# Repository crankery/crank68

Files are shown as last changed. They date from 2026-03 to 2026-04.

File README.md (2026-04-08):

# C68

One day I thought to myself I want to build a computer with the simplest 8 bit CPU I can think of". That CPU is the Motorola M6800 and this is the computer.

It's going to be pretty useless but it's fun to play around with all of this.

## Hardware

So, this isn't intended to be historically accurate or anything. It's a 1970s CPU but I'll use modern components where it makes things simpler. So, for whatever reason I thought it'd be nice to use things like the MC6850, MC6821 and other components that would have been available when the M6800 was being used in the industry. But really, I'm just trying to avoid using microcontrollers that would render the actual CPU hopelessly redundant.

One place I used a microcontroller is on the terminal board. It's just being used to produce DVI video and render text. Oh, it also does the keyboard matrix scan. It has its one job and that's to replace a glass terminal. So, since it's busy doing dumb terminal stuff it doesn't really matter that it's anacronistic... right?

The computer is split up across a bunch of 100x100mm boards. This is an attempt to reduce the cost of production as that's the maxiumum size the Chinese fabs will produce at bargain pricing. The one exception (thus far) is the actual keyboard; its dimensions are dictated by the keyboard layout.

I'm currently using some SPLDs as there were analogs of these back in the day. I am using them for decode logic for the most part but I'm trying to replace them with simple 74 series logic slowly.

### Boards

As previously mentioned, the computer is built upon a set of cards. These cards are generally single function so there's a lot of them. 

#### Backplane

The backplane is a simple board with a bunch of slots on it. Each board will plug into this board. The boards are setup to be chained together. The slots are 13.5mm apart giving about 12mm of component height for each board. If a board grows taller than this or has multiple layers, it will block the next slot. This is tall enough to allow for most common components though.

The left side of each board is allowed to host connectors. This allows for connecting I/O devices to individual boards such as parallel ports, serial ports, video output or sound output.

Status: C68BP.01 sent to production

#### Processor

This board hosts the Motorola M6800 CPU and the MC6875 clock generator along with an oscillator running at 4MHz. This will result in a 1MHz system clock.

Status: C68CPU.01 sent to production

#### Memory

Lower 48KB of RAM (in FRAM), 8KB ROM (EEPROM)

Status: C68MEM.01 sent to production

#### Banked Memory

1 MB of batery backed SRAM presented in two four KB windows in the main address space.

Status: Finalized design

#### Math

AMD AM9511 FPU

Status: design in progress

#### Sound

This is a sound board. I'm still trying to decide which chip(s) to use. The YM2149 OPL2, Philips SAA1099, GI AY-3-8910 SGM

Status: spitballing

#### IO

2xACIA MC6850, 2xPIA MC6821

Status: design completed

#### Time

A DS12885 RTC and a MC6850 PTC.

Status: design completed

#### Front Panel

blinkenlights and switches and buttons.

Status: in progress

#### Terminal

Using a Raspberry PI Pico with PicoDVI to generate the terminal's video and to perform keyboard scans. Uses an on-board MC6850 for communication to the host system.

Status: sent to production

## Software

The software for this project includes some old stuff and some new stuff. The old stuff is being "translated" into a VASM 6800 standard syntax while the new stuff is being written that way.

### Emulator

emu is a very basic M6800 emulator and is being used to verify software development. It isn't complete yet and will halt when it encounters an unimplemented instruction.

It is designed to match the actual computer's IO and memory access and will do the minimum to make things appear as they will in reality. So, the ACIA status and control registers set the flags appropriately while the actual rate of transfer isn't worried about.

### New Stuff

#### C68 BIOS

### Old Stuff

#### MIKBUG2

#### Micro Basic

## Tools

Everything is being done using open source tools. This includes, but is not limited to:

- kicad
- vasm
- vlink
- galasm
- minipro
- GCC

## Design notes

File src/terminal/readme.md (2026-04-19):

# pico-sdk

added as submodule here

we're just using this to build the picodvi so there's no point installing it globally.

to build the pico-sdk:

```sh
cd pico-sdk
git submodule update --init  
cmake -S . -B build
```

# picodvi

added as sumbodule here

```sh
cd picodvi/software
mkdir build
cd build
PICO_SDK_PATH=../../../pico-sdk cmake -DPICO_COPY_TO_RAM=1 ..
```

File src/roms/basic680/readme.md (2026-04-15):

# Altair 680 BASIC / Micro-soft BASIC for 6800

This is taken from https://gitlab.com/retroabandon/altair-680-basic which was an ambitious project to restore the assembly
source from a binary of Microsoft basic for the Altair 680 computer.

I'm trying to get assembling with vasm6800_oldstyle to run on my 6800 computer.

So, we're starting with a rough disassembly file. Getting this to build to match the binaries it was made from is the first goal.

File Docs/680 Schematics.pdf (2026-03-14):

9 | 8 | 7 | 6 | 5 | 4 | 3 | 2

§]

R/W-P

I

I

12 • | 2 I .. '-" | R/W"'! 13 | M | 0--.....- | .... _.. 2-C9, 3-09

-2 MHZ

-7 | 4'--- I
vce | TT
TbT | a
K 10 | 13 Q | II

9

8

. '---0

5

::10_

_3

CI2 50 pF

___ XTAL2

I-- | 2 MHZ
...1.. I | t | 6 | 10 | 6 | 4 | 2 | 10
9I yy | • 3 | 5 | 7 | 9 | II | 13 | 13 | II
tIW | I Ww. | yy | -
2 | 4 | 6 | "10 | If----+,:....:4-+_-f-lJ:::.2_--' ---4' | L.-...4.

J... C9

-,.. 430 pF .. R24

470 J\.

Q4
.... | R25 ... | 4 : .. 470.n- | 6
VC C ... | .. .. | R29 .. .. R 26 | 100 .no | --J
.. | 470 A | ..
..... | . Q':t :t | __8---\
:;r:. I OOI | 9 1ss R27 | JJF

4IIl" 470 A ,,:"
... | CIO
II 430 pF I
.... ,.,.,.,. ...

47.n..

I

:: RIO
.... 'OK ...

## vee

,-0
:.. R20 :

3.3K .

7

6
pp ;--0

IK ....

4 | 39 | 7 | 5 | 6 | 34 | 3 | 37 | 36 | 40
IRQ | TSC | BA | VMA | NMI | R/W | 01 | 02 | OBE | RES
6800 | NN
AI | A2 | A3 | A4 | A5 A6 | A7 A8 | A9 | AIO | All AI2 | AI3 AI4 | Al5 00 | 01 | 02 | 03 | 04 | 05 | 06 | 07
10 | II | 12 | 13 | 14 | 15 | 16 | 17 | 18 | '9 | 20 22 | 23 | 24 | 25 | 33 | 32 | 31 | 30 29 | 28 | 27 | 26
r--- | 2-D4, 3-C I
I 1..--- | 2-04, 3-C I
L--_a---------I | B05:-; | 2-04,3-CI ___---f----------I
B04 | 2-04, 3-CI
___ | .... 2-04,3-CI
S02 | 2-04,3-CI
F - 70-."'- r04 '-=- rl.-4-=- -;:;.- - rl.-.r rl.-....- | rl.- | rl.-.....- | -l'=- - | - •..=- | - ..-.... | I | SOl =- 2-04,3-CI
I lIIl>.... | | | ... | ... | >:. | :> 0!lI. | ..>.... | .. | 0Ill. | ..» | 4ll,. | ........ | ..> | .. | .. | .. | ... | ...> | ...> | .. | ... | ... PACKS | I | B00
:>:. | :..:. | :> | .. >.... | ...>..... | .. | ...> | .. | :.. | :> | :> | 1-4 | I | 2-04,3-CI
I ... > | .. | > | .. | .. | > | .... | .. .. | .. | ... | ... | ... | .. | ..... | <II> | ... | <l!" | ...> | ...> | 4.7 K
...: | : | : | : | : | : | : | : | ... : | : | ...::: | :::: | : : | :: | :::: | :::: | :::: | :: | :: | : | ... : | " | ...: | <II: | : | :-c: | I
L- | -_------------------------ --

vee ...-:111--1.--__--+--.....-+----+---+----+---..--+----

2-C9, 3-A4

2-C9,3-A4

2-C9,3-A5 ::---+----+---w

2-C9,3-AS

2-C9,3-A6

2

### 8 HALT -

F A'

9

2-09,
2-09,

2-09,3-

2-09,3-AS

2-09,

I | 2-09,3
| 2-09,3
| 2-09, 2-C9,3-A4 .:

c

HALT | IRQ | T-se | BA | VMA | NMJ | Riw | ,pI | 92 | DBE | RES
/ | I | I | /\ | Ii'- | I | /\ | l' 1 | I
2-AS ..:; lSI | (12::: | C9
D | C9 :: R/W | r Z

2- | 09
2- A4_ TRQ | 3 | 5 | A23
2- 84 | ..A ••••
| ,.,.,.,.
10 | 47.n.
pp

9

\j; | tv | I | I | I
\V \/ | \( \/ | \V \/ | \/ \V | \V \V | \V \V | V \/ | ¥W | \t' \V | \/ \V | \l;
A¢ | Ai | A2 | A3 | A4 | A5 AS | A7 | AS | A9 | AIO | All Af2 | AI3 AI4 | AI5 | Df | 02 | D3 04 | 05 | 06 | D7
[!]@] | EJEO

\V

BO¢

\/

BOI

\/

BD 2
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
SO 6

\v

B07 | 68"0 COMPUTER SCHEMATIC
ACR | 5-4-76

9 | 8 | 7 | 6 | 3 | 2

J I

+5V
R401
IK

R202
IK

R204
470..n..

R203
220..n..

JI

.--,

I | 4 | I
E4 | -:::::=v-;---

L __ .J

-16V

R303
3.3 K

+5V

.....----I ,.. '_ .,

I 3 I
______E::.-3__-:-.:

L __ .J

+5V

6

.... ES'

L | .J

E5

RIOI
220..1\..
RS 232

!

... I-BI
i- B I

L...---...;;;..-.......
1- B1
I-AI
I- AI
1- AI
1- AI

## IRQ

I-D9

2 Rx
DATA
Rx | 3
II | RS | elK
4 13 R/W | Tx
| | ClK
E
14 | +5V

t5V

MM
13 | 12 | 10 CSt
.jJ

I
t::

R21
IS...n..

+5V

2W
+SV (VCC) | 8

RS 232

+

6

C3
35j1F
15V

VCC
6

R9
4.7K -9V +5V

C5
+ 100jJF

2

10

# a-=------------.-TII-..,..----=-4l-

U

u ",,--S---a._-+--_

:3

B

AI5
1-89.3-A7
Al4
1- B9, 3-A7
AI3
1-89.3-A7
D | Al2
1- B 9, 3-A8
| All
1-89.3-A8
| AIO
1- B9, 3- A8
| A9
I-B9,3-A6
| A 8
1-89,3-A6
| VMA
1-08
A7 1-89,3-A5
| A 6
1-89,3-A5
AS 1-89,3-AS
| A4
1- 89, 3-A5
| A3
1-89,3-A5
A2 I-A9,3-A5
| AI
1- A9, 3-A5
C | A0
1- A9. 3-A6
R/W 1-07

02 1-06

| R/W-P
1- BI • 3-D 9

## [!gJ -16 V

+16V

@] +9V

9 | 8 | 7 | 5 | 4 | 3 | 2
REF | TYPE | GNO
A.B,C,D,r | 74LS05 | 14 | 7
H/13, E/13 | 4009 OR | 16 | 8 F/13,G/13 | 4049
.1/11,12,13 74LOO | 14 | 7
K/II,12 | 74LI23 | 16 | 8 L/3,4,11,12

....----+--+----+--+-1680 0ISPLAY SCHEMATIC

DO EJ

01

02

03

04

05

06 §J

07

02

GNO 150,1001

VCC

L027
(HALT)

R34
lOOK

Q

## vec

CLR
II | R39 | VCC
10K | f::l L..- | --+ | ---< QJ I I.!!J

LDI7

Q 13

CLR

RESET rs4l OP

Q

9

## vee

CLR
II

R40
10K

## vee

VCC

Q 13

R33
4.7
(RUN) | R41 0 | lOA-
(DEP) | S2:(HALTl
I J: | 2 | II I- | 10

B RI7
| 20K | , (HALT)
510 | RIO
___

# §lSA

A

0
AO

At

@] A2

A3

A4

A5

C
@] A6

0 A7

# §l AS

(2JA9

o AIO

o All

B
§] AI2

AI3

§] AI4

§] AIS

.---+-+-----t----t--1 A. C. R.

680-100
SHT40F4

••fO"_ATtO •••T.oaTIIO.TMlaDOCU•••TAW. TNt: DWa.. itO. P.OPI..Tl' O,. ••T•• I.C. A.D.N...LL.OT ••••••ODUCI:D

'O•••,..".."O.lEOy.... TM... TMAT'O••"ICM ITW.I

•• | WIT"OUT Till! •••TT•• --;- | ----. | --;--_---.----__

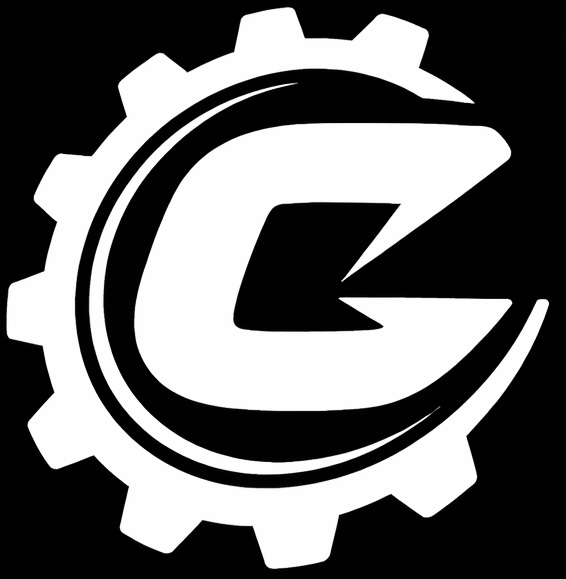
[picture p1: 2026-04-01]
Docs/Crank.jpg

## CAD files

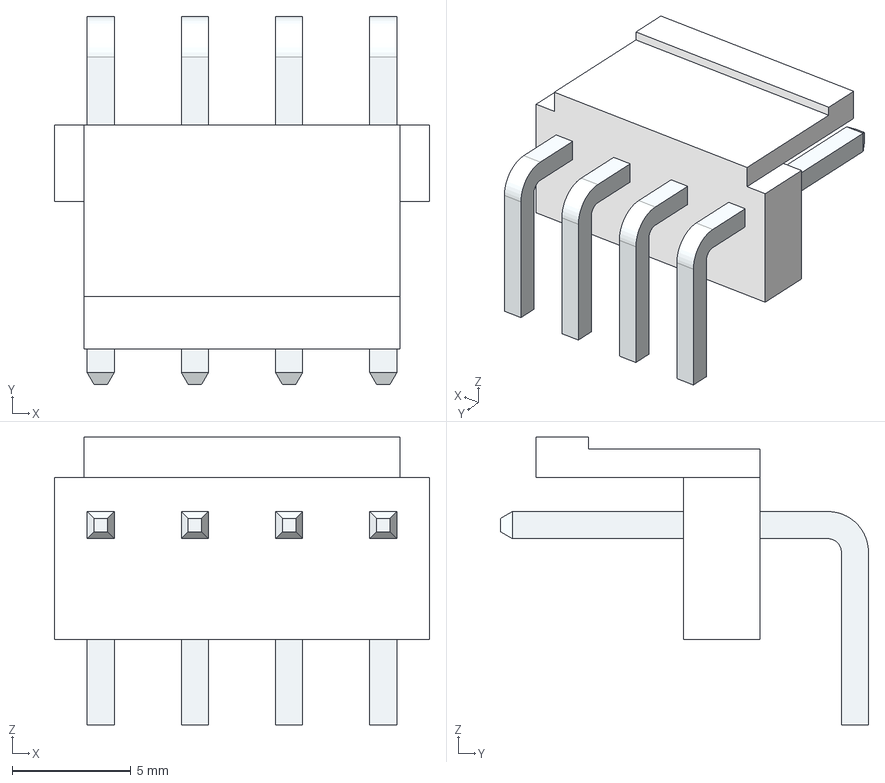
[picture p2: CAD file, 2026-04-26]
3D/B4PS-VH.stp
15.8 x 15.5 x 12.1 mm

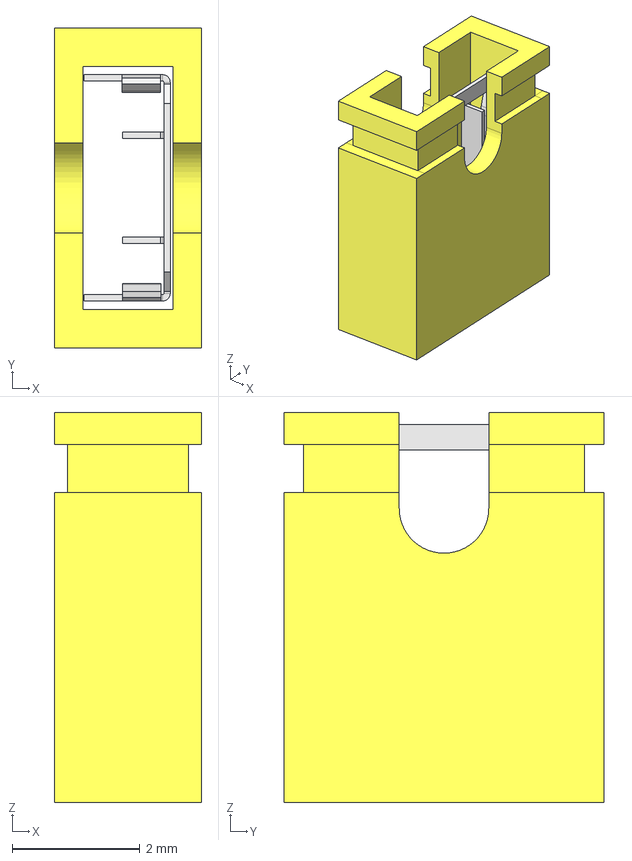
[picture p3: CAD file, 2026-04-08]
3D/Jumper.step
2.30 x 5.00 x 6.10 mm
Frame
Jump

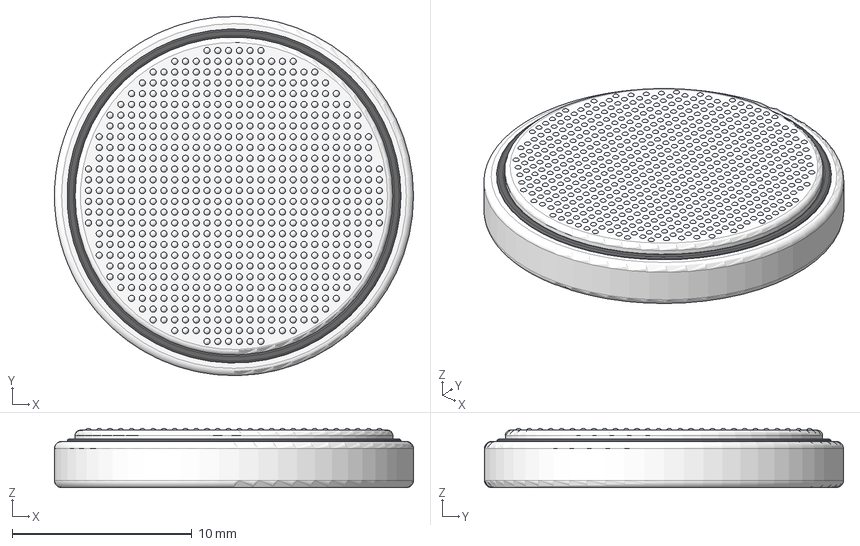
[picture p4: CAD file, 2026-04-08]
3D/CR2032.step
20.0 x 20.0 x 3.30 mm

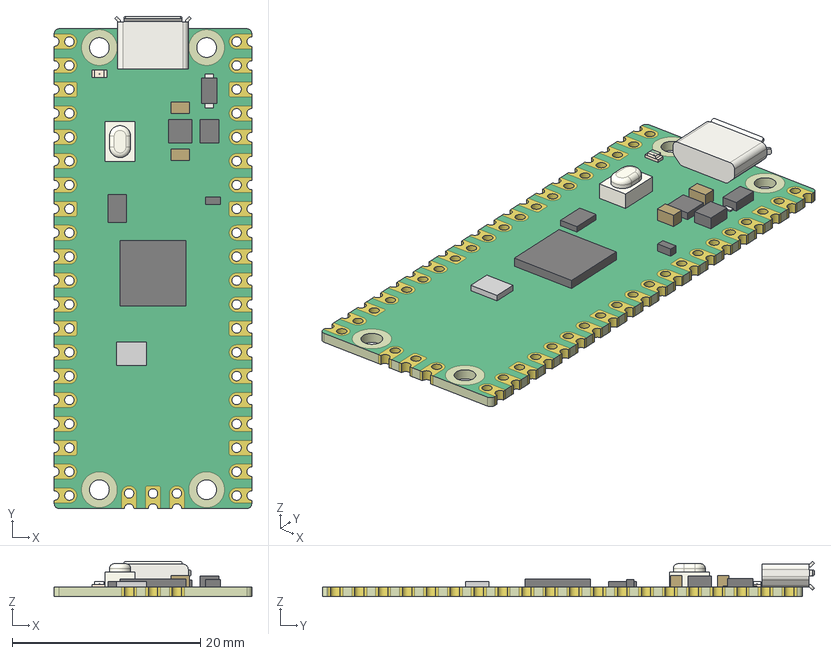
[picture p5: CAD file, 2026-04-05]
3D/RaspberryPi_Pico.step
21.0 x 52.3 x 3.75 mm

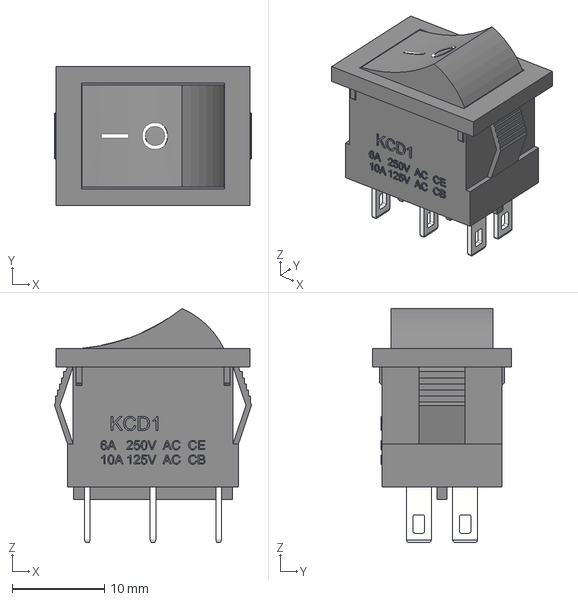
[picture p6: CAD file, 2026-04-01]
3D/Rocker Switch 11.step
21.3 x 15.0 x 25.3 mm

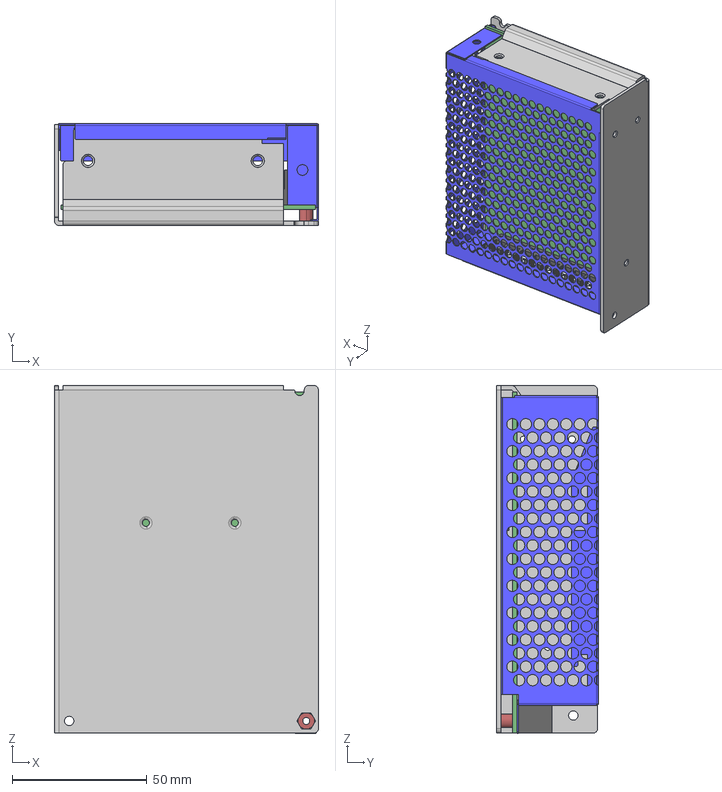
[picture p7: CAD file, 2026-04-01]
3D/RT-65.stp
98.1 x 37.8 x 129.2 mm
DUNZI-S-8P_1.PRT
RG-65-PCB_1.PRT
CUUU_1.PRT
90T-T_6.PRT
903-D_11.PRT

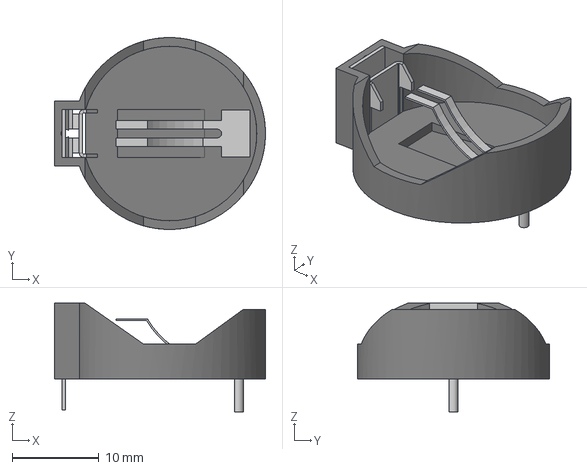
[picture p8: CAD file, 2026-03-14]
3D/KLS5-CR2032-01 battery holder.stp
24.3 x 22.1 x 12.5 mm

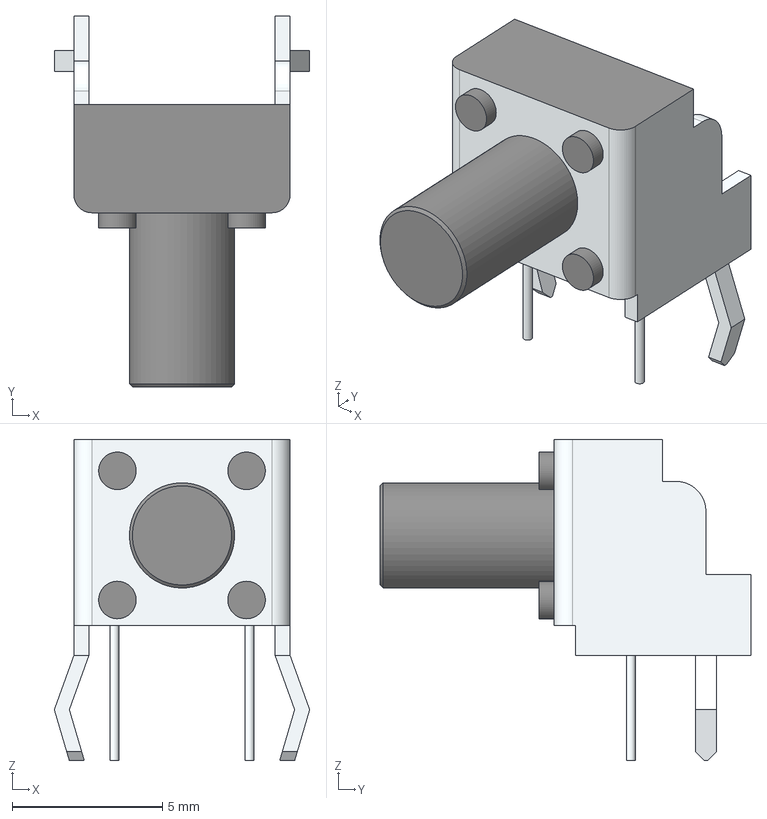
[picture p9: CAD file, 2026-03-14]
3D/SW-DTSA-65K-V.stp
8.50 x 12.3 x 10.7 mm

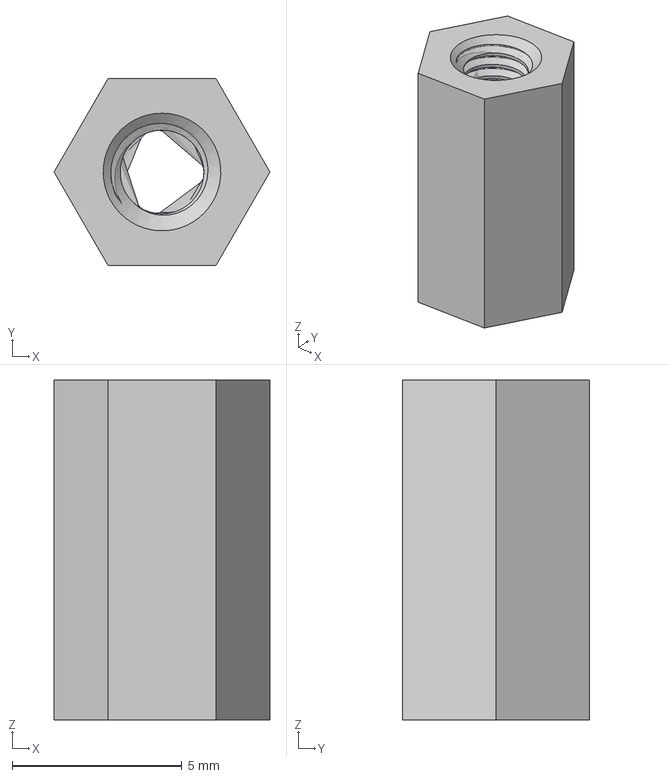
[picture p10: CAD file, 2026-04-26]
3D/hex spacer standoff nut_M3 L10.stp
6.35 x 5.50 x 10.0 mm

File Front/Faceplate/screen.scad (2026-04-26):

$fn = 32;

panel_w = 118.0;
panel_h = 89.0;
panel_d = 6.0;

bezel_w = 5;
overall_d = 8;

insert_hole_d = 3.5;

bighole_d =  (panel_w - bezel_w / 4) / 5;

difference() {
    cube([panel_w+bezel_w*2, panel_h+bezel_w*2, overall_d]);
    translate([bezel_w, bezel_w, -0.1])
      cube([panel_w, panel_h, panel_d]);
  
  translate([2.5-1.75, bezel_w/2 + insert_hole_d/2, -0.1])
    cylinder(h = overall_d + 1, r = insert_hole_d / 2, center = true);
  
  translate([panel_w  + bezel_w + insert_hole_d/2,(bezel_w/2 + insert_hole_d)/2, -0.1])
    cylinder(h = overall_d + 1, r = insert_hole_d / 2);  
  
  // save some plastic...
  translate([bezel_w * 2 + bighole_d / 2, bezel_w * 2 + bighole_d / 2, 0.1])
    cylinder(h = 10, , r = bighole_d / 2);

  translate([bezel_w * 2 + bighole_d / 2, bezel_w * 2 + bighole_d / 2, 0.1])
    cylinder(h = 10, , r = bighole_d / 2);

  translate([bezel_w * 3 + bighole_d +  bighole_d / 2, bezel_w * 2 + bighole_d / 2, 0.1])
    cylinder(h = 10, , r = bighole_d / 2);

  translate([bezel_w * 4 + bighole_d* 2 +  bighole_d / 2, bezel_w * 2 + bighole_d / 2, 0.1])
    cylinder(h = 10, , r = bighole_d / 2);

  translate([bezel_w * 5 + bighole_d* 3 +  bighole_d / 2, bezel_w * 2 + bighole_d / 2, 0.1])
    cylinder(h = 10, , r = bighole_d / 2);
    
  translate([bezel_w * 2 + bighole_d / 2, bezel_w * 3 + bighole_d + bighole_d / 2, 0.1])
    cylinder(h = 10, , r = bighole_d / 2);

  translate([bezel_w * 3 + bighole_d +  bighole_d / 2, bezel_w * 3 + bighole_d + bighole_d / 2, 0.1])
    cylinder(h = 10, , r = bighole_d / 2);

  translate([bezel_w * 4 + bighole_d* 2 +  bighole_d / 2, bezel_w * 3 + bighole_d + bighole_d / 2, 0.1])
    cylinder(h = 10, , r = bighole_d / 2);

  translate([bezel_w * 5 + bighole_d* 3 +  bighole_d / 2, bezel_w * 3 + bighole_d + bighole_d / 2, 0.1])
    cylinder(h = 10, , r = bighole_d / 2);
    
  translate([bezel_w * 2 + bighole_d / 2, bezel_w * 4 + bighole_d * 2 + bighole_d / 2, 0.1])
    cylinder(h = 10, , r = bighole_d / 2);

  translate([bezel_w * 3 + bighole_d +  bighole_d / 2, bezel_w * 4 + bighole_d * 2+ bighole_d / 2, 0.1])
    cylinder(h = 10, , r = bighole_d / 2);

  translate([bezel_w * 4 + bighole_d* 2 +  bighole_d / 2, bezel_w * 4 + bighole_d * 2+ bighole_d / 2, 0.1])
    cylinder(h = 10, , r = bighole_d / 2);

  translate([bezel_w * 5 + bighole_d* 3 +  bighole_d / 2, bezel_w * 4 + bighole_d * 2+ bighole_d / 2, 0.1])
    cylinder(h = 10, , r = bighole_d / 2);
}

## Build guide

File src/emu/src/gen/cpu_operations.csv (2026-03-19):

opcode_byte | mnemonic | addr_mode | cycles
0x01 | nop | inh | 2
0x06 | tap | inh | 2
0x07 | tpa | inh | 2
0x08 | inx | inh | 2
0x09 | dex | inh | 2
0x0a | clv | inh | 2
0x0b | sev | inh | 2
0x0c | clc | inh | 2
0x0d | sec | inh | 2
0x0e | cli | inh | 2
0x0f | sei | inh | 2
0x10 | sba | inh | 2
0x11 | cba | inh | 2
0x16 | tab | inh | 2
0x17 | tba | inh | 2
0x19 | daa | inh | 2
0x1b | aba | inh | 2
0x20 | bra | rel | 3
0x22 | bhi | rel | 3
0x23 | bls | rel | 3
0x24 | bcc | rel | 3
0x25 | bcs | rel | 3
0x26 | bne | rel | 3
0x27 | beq | rel | 3
0x28 | bvc | rel | 3
0x29 | bvs | rel | 3
0x2a | bpl | rel | 3
0x2b | bmi | rel | 3
0x2c | bge | rel | 3
0x2d | blt | rel | 3
0x2e | bgt | rel | 3
0x2f | ble | rel | 3
0x30 | tsx | inh | 2
0x31 | ins | inh | 2
0x32 | pula | inh | 2
0x33 | pulb | inh | 2
0x34 | des | inh | 2
0x35 | txs | inh | 2
0x36 | psha | inh | 2
0x37 | pshb | inh | 2
0x39 | rts | inh | 5
0x3b | rti | inh | 9
0x3e | wai | inh | 9
0x3f | swi | inh | 12
0x40 | nega | inh | 2
0x43 | coma | inh | 2
0x44 | lsra | inh | 2
0x46 | rora | inh | 2
0x47 | asra | inh | 2
0x48 | asla | inh | 2
0x49 | rola | inh | 2
0x4a | deca | inh | 2
0x4c | inca | inh | 2
0x4d | tsta | inh | 2
0x4f | clra | inh | 2
0x50 | negb | inh | 2
0x53 | comb | inh | 2
0x54 | lsrb | inh | 2
0x56 | rorb | inh | 2
0x57 | asrb | inh | 2
0x58 | aslb | inh | 2
0x59 | rolb | inh | 2
0x5a | decb | inh | 2
0x5c | incb | inh | 2
0x5d | tstb | inh | 2
0x5f | clrb | inh | 2
0x60 | neg | idx | 4
0x63 | com | idx | 4
0x64 | lsr | idx | 4
0x66 | ror | idx | 4
0x67 | asr | idx | 4
0x68 | asl | idx | 4
0x69 | rol | idx | 4
0x6a | dec | idx | 4
0x6c | inc | idx | 4
0x6d | tst | idx | 4
0x6e | jmp | idx | 4
0x6f | clr | idx | 4
0x70 | neg | ext | 4
0x73 | com | ext | 4
0x74 | lsr | ext | 4
0x76 | ror | ext | 4
0x77 | asr | ext | 4
0x78 | asl | ext | 4
0x79 | rol | ext | 4
0x7a | dec | ext | 4
0x7c | inc | ext | 4
0x7d | tst | ext | 4
0x7e | jmp | ext | 4
0x7f | clr | ext | 4
0x80 | suba | imb | 2
0x81 | cmpa | imb | 2
0x82 | sbca | imb | 2
0x84 | anda | imb | 2
0x85 | bita | imb | 2
0x86 | ldaa | imb | 2
0x88 | eora | imb | 2
0x89 | adca | imb | 2
0x8a | oraa | imb | 2
0x8b | adda | imb | 2
0x8c | cpx | imw | 3
0x8d | bsr | rel | 7
0x8e | lds | imw | 3
0x90 | suba | dir | 3
0x91 | cmpa | dir | 3
0x92 | sbca | dir | 3
0x94 | anda | dir | 3
0x95 | bita | dir | 3
0x96 | ldaa | dir | 3
0x97 | staa | dir | 3
0x98 | eora | dir | 3
0x99 | adca | dir | 3
0x9a | oraa | dir | 3
0x9b | adda | dir | 3
0x9c | cpx | dir | 3
0x9e | lds | dir | 3
0x9f | sts | dir | 3
0xa0 | suba | idx | 4
0xa1 | cmpa | idx | 4
0xa2 | sbca | idx | 4
0xa4 | anda | idx | 4
0xa5 | bita | idx | 4
0xa6 | ldaa | idx | 4
0xa7 | staa | idx | 4
0xa8 | eora | idx | 4
0xa9 | adca | idx | 4
0xaa | oraa | idx | 4
0xab | adda | idx | 4
0xac | cpx | idx | 4
0xad | jsr | idx | 6
0xae | lds | idx | 4
0xaf | sts | idx | 4
0xb0 | suba | ext | 4
0xb1 | cmpa | ext | 4
0xb2 | sbca | ext | 4
0xb4 | anda | ext | 4
0xb5 | bita | ext | 4
0xb6 | ldaa | ext | 4
0xb7 | staa | ext | 4
0xb8 | eora | ext | 4
0xb9 | adca | ext | 4
0xba | oraa | ext | 4
0xbb | adda | ext | 4
0xbc | cpx | ext | 4
0xbd | jsr | ext | 7
0xbe | lds | ext | 4
0xbf | sts | ext | 4
0xc0 | subb | imb | 2
0xc1 | cmpb | imb | 2
0xc2 | sbcb | imb | 2
0xc4 | andb | imb | 2
0xc5 | bitb | imb | 2
0xc6 | ldab | imb | 2
0xc8 | eorb | imb | 2
0xc9 | adcb | imb | 2
0xca | orab | imb | 2
0xcb | addb | imb | 2
0xce | ldx | imw | 3
0xd0 | subb | dir | 3
0xd1 | cmpb | dir | 3
0xd2 | sbcb | dir | 3
0xd4 | andb | dir | 3
0xd5 | bitb | dir | 3
0xd6 | ldab | dir | 3
0xd7 | stab | dir | 3
0xd8 | eorb | dir | 3
0xd9 | adcb | dir | 3
0xda | orab | dir | 3
0xdb | addb | dir | 3
0xde | ldx | dir | 3
0xdf | stx | dir | 3
0xe0 | subb | idx | 4
0xe1 | cmpb | idx | 4
0xe2 | sbcb | idx | 4
0xe4 | andb | idx | 4
0xe5 | bitb | idx | 4
0xe6 | ldab | idx | 4
0xe7 | stab | idx | 4
0xe8 | eorb | idx | 4
0xe9 | adcb | idx | 4
0xea | orab | idx | 4
0xeb | addb | idx | 4
0xee | ldx | idx | 4
0xef | stx | idx | 4
0xf0 | subb | ext | 4
0xf1 | cmpb | ext | 4
0xf2 | sbcb | ext | 4
0xf4 | andb | ext | 4
0xf5 | bitb | ext | 4
0xf6 | ldab | ext | 4
0xf7 | stab | ext | 4
0xf8 | eorb | ext | 4
0xf9 | adcb | ext | 4
0xfa | orab | ext | 4
0xfb | addb | ext | 4
0xfe | ldx | ext | 4
0xff | stx | ext | 4

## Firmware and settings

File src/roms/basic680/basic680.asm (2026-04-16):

; f9dasm: M6800/1/2/3/8/9 / H6309 Binary/OS9/FLEX9 Disassembler V1.79
; Loaded Motorola S file basic680.mot

;****************************************************
;* Used Labels                                      *
;****************************************************

M1B1B   EQU     $1B1B
M22F1   EQU     $22F1
M2505   EQU     $2505
M2E4F   EQU     $2E4F
M2FC1   EQU     $2FC1
M3BD7   EQU     $3BD7
M46BD   EQU     $46BD
M49C4   EQU     $49C4
M52C7   EQU     $52C7
M55C6   EQU     $55C6
M6828   EQU     $6828
M7960   EQU     $7960
M7A88   EQU     $7A88
M7D5A   EQU     $7D5A
M7D9A   EQU     $7D9A
M7FFF   EQU     $7FFF
M8180   EQU     $8180
M8607   EQU     $8607
M863F   EQU     $863F
M8D97   EQU     $8D97
M942E   EQU     $942E
M9474   EQU     $9474
MA100   EQU     $A100
MC608   EQU     $C608
MC60E   EQU     $C60E
MC628   EQU     $C628
MC62C   EQU     $C62C
MDE9E   EQU     $DE9E
ME47F   EQU     $E47F
MEA60   EQU     $EA60
MF002   EQU     $F002
MF600   EQU     $F600
MFC18   EQU     $FC18
INCH    EQU     $FF00
POLCAT  EQU     $FF24
OUTCH   EQU     $FF81
MFFFF   EQU     $FFFF

;****************************************************
;* Program Code / Data Areas                        *
;****************************************************

        ORG     $0000

START   SEC
        ROR     >M00F3
RDYJSR  JMP     INIT                     ; !!! INIT replaces with JSR READY (warm start)
M0007   JMP     Z033C
M000A   FCB     $00
M000B   FCB     $00
M000C   FCC     "H"
M000D   FCC     "8"
M000E   FCB     $00
M000F   FCC     ","
M0010   FCB     $00,$00,$00,$00,$00,$00,$00,$00,$00,$00,$00,$00,$00
        FCB     $00,$00,$00,$00,$00,$00,$00,$00,$00
M0026   FCB     $00,$00,$00,$00,$00,$00,$00,$00,$00,$00,$00,$00,$00
        FCB     $00,$00
M0035   FCB     $00,$00,$00,$00,$00,$00,$00,$00,$00,$00,$00,$00,$00
        FCB     $00
M0043   FCB     $00,$00,$00,$00,$00,$00,$00,$00,$00,$00,$00,$00
M004F   FCB     $00,$00,$00,$00,$00,$00,$00,$00,$00
CHARAC  FCB     $00
ENDCHR  FCB     $00
M005A   FCB     $00
M005B   FCB     $00
M005C   FCB     $00
M005D   FCB     $00
M005E   FCB     $00
M005F   FCB     $00
M0060   FCB     $00
TEMPPT  FCB     $00,$00
M0063   FCB     $00,$00
M0065   FCB     $00,$00,$00,$00,$00,$00,$00,$00,$00,$00,$00,$00
M0071   FCB     $00
M0072   FCB     $00
M0073   FCB     $00
M0074   FCB     $00
M0075   FCB     $00
M0076   FCB     $00
M0077   FCB     $00
stktmp  FCB     $00                      ; temp storage for S when using for copy
M0079   FCB     $00
M007A   FCB     $00
M007B   FCB     $00
M007C   FCB     $00
M007D   FCB     $00
M007E   FCB     $00
M007F   FCB     $00
M0080   FCB     $00
M0081   FCB     $00
M0082   FCB     $00
M0083   FCB     $00
M0084   FCB     $00
M0085   FCB     $00
M0086   FCB     $00,$00
M0088   FCB     $00
M0089   FCB     $00
M008A   FCB     $00
M008B   FCB     $00
M008C   FCB     $00,$00
M008E   FCB     $00
M008F   FCB     $00
M0090   FCB     $00
M0091   FCB     $00
M0092   FCB     $00,$00
M0094   FCB     $00
M0095   FCB     $00
M0096   FCB     $00,$00
M0098   FCB     $00,$00
M009A   FCB     $00
M009B   FCB     $00
M009C   FCB     $00
M009D   FCB     $00
M009E   FCB     $00
M009F   FCB     $00
M00A0   FCB     $00,$00
M00A2   FCB     $00
copy_dsttop FCB     $00,$00                  ; top of destination range for `copy`
copy_srctop FCB     $00,$00                  ; top of source range for `copy`
copy_dstbot FCB     $00,$00                  ; bottom of dest range for copy
                                         ;   (filled in at end of `copy`)
copy_srcbot FCB     $00,$00                  ; 1 below bottom of dest range for `copy`
M00AB   FCB     $00
M00AC   FCB     $00
M00AD   FCB     $00
M00AE   FCB     $00
tmpstrlen FCB     $00
DSCTMP  FCB     $00,$00
M00B2   FCB     $00
M00B3   FCB     $00
M00B4   FCB     $00
M00B5   FCB     $00
M00B6   FCB     $00
M00B7   FCB     $00
M00B8   FCB     $00
M00B9   FCB     $00
M00BA   FCB     $00
STRNG1  FCB     $00
M00BC   FCB     $00
STRNG2  FCB     $00
M00BE   FCB     $00

Z00BF   INC     >M00C9
        BNE     Z00C7
        INC     >M00C8
Z00C7   LDAA    MEA60                    ; This abs. address incremented above
        CMPA    #$3A
        BCC     Z00D6
        CMPA    #$20
        BEQ     Z00BF
        SUBA    #$30
        SUBA    #$D0
Z00D6   RTS
Z00D7   STX     MEA60
        JMP     Z03C7

; Another data section?
        FCB     $00,$00,$00,$06,$06,$06,$06,$06,$06,$04,$FF,$FD,$FF
        FCB     $FD,$FF,$FF,$FF,$FD,$FD,$FF,$FD,$FD
M00F3   FCB     $00,$FD,$FF,$FD,$FD,$FD,$FF,$FD,$FF,$FF
        FCC     "d"
M00FE   FCC     "`"
M00FF   FCB     $FD
M0100   FCB     $00,$00,$00,$00,$00,$00,$00,$00,$00,$00,$00,$00,$00
M010D   FCB     $80
        FCC     "O"
        FCB     $C7
        FCC     "R"
M0111   FCB     $00

x0112   JMP     INIT                     ; !!! INIT replaces dest with STROUT

        FCB     $0C,$D8,$0E
        FCC     "4"

M0119   FCB     $14,$90,$15,$04,$14,$AA,$0D
        FCC     "L"
        FCB     $0E,$15,$0E
        FCC     "@"
        FCB     $16,$FC,$17,$DC,$12,$D2,$17
        FCC     "h"
M012D   FCB     $18,$12
M012F   FCB     $18,$18
M0131   FCB     $18
        FCC     "^"
M0133   FCB     $18,$A2,$11,$8D,$10,$A9,$0E,$F1,$11
        FCC     "J"
        FCB     $10,$C9,$10,$B5,$10,$D1,$10,$EE,$10,$F5
M0147   FCC     "y"
        FCB     $11,$C7
        FCC     "y"
        FCB     $11,$BC
        FCC     "{"
        FCB     $13,$0A
        FCC     "{"
        FCB     $13,$BE,$7F,$17,$05
        FCC     "P"
        FCB     $0B,$96
        FCC     "F"
        FCB     $0B
M015B   FCB     $95
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

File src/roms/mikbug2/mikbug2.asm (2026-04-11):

*
* CONVERTED TO AN ASSEMBLY FILE FROM A CRAPPY PDF BY
* MEMBERS OF THE MOTOROLA 6809 / 6309, 6800 ASSEMBLY
* LANGUAGE PROGRAMMING FACEBOOK GROUP
* BY CRAIG JONES,RAY BELLIS
*

*>
*>	.section .stack, "au", @nobits
*>
*>stack:	.space 0x100
*>

*       NAM    MIKBUG
*       TTL    2.0 WITH AUDIO CASSETTE
*     REV  0
*     COPYRIGHT (C)  1977  BY MOTOROLA INC.
*
*     MIKBUG (TM) MOTOROLA
*
*     AUSTIN, TEXAS
*     MICROCOMPUTER CAPITAL OF THE WORLD!
*
*     L  LOAD
*     M  MEMORY CHANGE
*     P  PRINT/PUNCH DUMP
*     R  DISPLAY CONTENTS OF TARGET STACK
*          CC   B   A   X   P   S
*     S  1,SET SPEED FOR 10 CPS
*        3,SET SPEED FOR 30 CPS
*     B  PRINT OUT ALL BREAKPOINTS
*     C  CONTINUE EXECUTION FROM CURRENT LOCATION
*     N  NEXT INSTRUCTION
*     T  TRACE 'N' INSTRUCTIONS
*     G  GO TO LOCATION 'N'
*     D  DELETE ALL BREAKPOINTS
*     U  RESET BREAKPOINT WITH ADDRESS 'N'
*     V  SET A BREAKPOINT WITH ADDRESS 'N'
*     E  EXORTAPE CASSETTE INTERFACE
*
*<       OPT    S,O,LLEN=80,CREF
*<ACIAS  EQU    $8008
*<ACIAD  EQU    $8009
*<SWI   EQU    $3F      SWI OP CODE
*>	.equ swiop, 0x3f      ; swi op code

*<       ORG    $F800
*<BASORG   EQU    *        BASE ORIGIN
*>	.section .mmio, "au", @nobits
*>
*>acias:	.space 0x01
*>aciad:	.space 0x01
*>
*>	.space 0x100-0x02
*>
*>	.section .rom, "ax"
*>
*>baseorg:

*
*     I/O INTERRUPT SEQUENCE
*
IO     LDX    IOV
	JMP    0,X
*
*     NMI SEQUENCE
*
POWDWN LDX    NIO      GET NMI VECTOR
	JMP    0,X
*
*     SWI INTERRUPT SEQUENCE
*
SFEI   LDX    SWI1
	JMP    0,X
*
* JUMP TABLE TO ROUTINES PERFORMING MIKBUG FCTN'S
*
FCTABL EQU    *
	FCC    /B/      "B" - PRINT ALL BREAKS
	FDB    PNTBRK
	FCC    /C/      "C" - CONTINUE
	FDB    CONT
	FCC    /D/      "D" - DELETE ALL BREAKS
	FDB    DELBRK
	FCC    /G/      "G" - GO TO ENTERED ADDRESS
	FDB    GOTO
	FCC    /L/      "L" - LOAD
	FDB    LOAD
	FCC    /M/      "M" - MEMORY CHANGE
	FDB    CHANGE
	FCC    /N/      "N" - NEXT (TRACE 1 INSTR)
	FDB    NEXT
	FCC    /P/      "P" - PUNCH
	FDB    PUNCH
	FCC    /R/      "R" - PRINT STACK
	FDB    PSTAK1
	FCC    /S/      "S" - CHANGE SPEED FOR TTY
	FDB    SPD
	FCC    /T/      "T" - TRACE N INSTRUCTIONS
	FDB    TRACE
	FCC    /U/      "U" - RESET A BREAKPOINT
	FDB    RSTBRK
	FCC    /E/      "E" - EXORTAPE CASSETT INTERFACE
	FDB    EXORT
	FCC    /V/      "V" - SET A BREAKPOINT
	FDB    SETBRK
FCTBEN EQU    *
*
*      INITIALIZATION/RESET CODE
*
ADRSTR EQU    *
	FDB    STACK    INIT FOR "SP"
	FDB    SWI15    INIT FOR "SWI1"
	FDB    BRKINH   INIT FOR "SWI2"
*
	BRA    BRG      "BRA" INST IS REPLACED BY
	JMP    BRNOGO   COND BRA INST IN ROUT.
BRG    JMP    BRGO     WHICH DETERMINES IF
*                      BRA IS GO/NOGO
*
* BUILD ADDRESS
*
BADDR  BSR    BYTE     READ 2 FRAMES
	STAA   XHI
	BSR    BYTE
	STAA   XLOW
	LDX    XHI      (X) ADDRESS WE BUILT
	RTS
* INPUT BYTE (TWO FRAMES)
BYTE   BSR    INHEX    GET HEX CHAR
BYTE2  ASLA
	ASLA
	ASLA
	ASLA
	TAB
	BSR    INHEX
	ABA
	TAB
	ADDB   CKSM
	STAB   CKSM
	RTS
OUTHL  LSRA            OUT HEX LEFT BCD DIGIT
	LSRA
	LSRA
	LSRA
OUTHR  ANDA   #$F      OUT HEX RIGHT BCD DIGIT
	ADDA   #$30
	CMPA   #$39
	BLS    OUTCH
	ADDA   #$7
* OUTPUT ONE CHAR
OUTCH  JMP    OUTCH1
INCH   JMP    INCH1
* PRINT DATA POINTED AT BY X-REG
PDATA2 BSR    OUTCH
	INX
PDATA1 LDAA   0,X
	CMPA   #4
	BNE    PDATA2
	RTS             STOP ON EOT
*
* INPUT ADDRESS
*
GETADD BSR    PCRLF    PRINT  CR LF
	LDX    #MCL4
	BSR    PDATA1   ASK FOR BEGADDR
	BSR    BADDR    GET BEG ADDR
	STX    BEGA
	BSR    PCRLF    PRINT CR LF
	LDX    #MCL5
	BSR    PDATA1   ASK FOR END ADDR
	BSR    BADDR    GET END ADDRESS
	STX    ENDA
	RTS             *
* PRINT CR LF
*
PCRLF  STX    XHI      SAVE XR
	LDX    #MCL1
	BSR    PDATA1   PRINT CRLF
	LDX    XHI
	RTS
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

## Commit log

2026-03-14 Probably should start tracking changes
    [Backplane.kicad_pcb, Backplane.kicad_sch, IO.kicad_pcb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]
2026-03-15 start with AY-3-8910/SAA1099 sound card
    [Sound.kicad_pcb, Sound.kicad_sch]
2026-03-15 added galasm ref
    [Sound.kicad_pcb]
2026-03-17 seems to die where it should
2026-03-17 ye olde checkpointe
    [Front.kicad_pcb, Front.kicad_sch]
2026-03-18 i'm going to bed.
2026-03-19 maybe it'd be an idea to move the kicad projects into their own folder... the gitignore was hiding my operations .csv file.
    [m6800_ops.csv]
2026-03-21 kinda works
    [m6800_ops.csv]
2026-03-21 runs the whole fake bios now... time to get some sort of console going
    [cpu_operations.csv]
2026-03-22 outputs to terminal/log file
    [Memory.kicad_pcb, Memory.kicad_sch, Sound.kicad_sch]
2026-03-24 switch to daily sources for vasm/vlink
2026-04-01 a bunch of stuff
    [Backplane.kicad_pcb, Backplane.kicad_sch, BankedMemory.kicad_pcb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]
2026-04-02 mostly updating keyboard
    [Keyboard-B_Cu.gbr, Keyboard-B_Mask.gbr, Keyboard-B_Paste.gbr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]
2026-04-02 update the backplane
    [Backplane-B_Cu.gbr, Backplane-B_Mask.gbr, Backplane-B_Paste.gbr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]
2026-04-05 ordered v01 of the cpu
    [ClockTest.kicad_pcb, ClockTest.kicad_sch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]
2026-04-05 ordered memory board
    [Memory-B_Cu.gbr, Memory-B_Mask.gbr, Memory-B_Paste.gbr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]
2026-04-06 finish layout on time board. still need to verify RTC's multiplexed IO
    [Time.kicad_pcb, Time.kicad_sch]
2026-04-06 mainly actually saving out vs.code along with sorting out the math card
    [Math.kicad_pcb, Math.kicad_sch, Oddity.kicad_pcb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]
2026-04-08 finish routing the coms board. add some step models to look at this thing in freecad
    [Backplane.kicad_pcb, BankedMemory.kicad_pcb, BankedMemory.kicad_sch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]
2026-04-08 oops, forgot some files
    [BankedMemory-B_Cu.gbr, BankedMemory-B_Mask.gbr, BankedMemory-B_Paste.gbr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]
2026-04-08 fat fingers
2026-04-10 ugh. resetting...
    [Time.kicad_sch]
2026-04-11 start moving towards helper methods on the cpu operations
    [Time.kicad_sch]
2026-04-12 added a bunch of debugging to emu, fixed a pile of translation issues on mikbug2. more to go
    [Time.kicad_pcb]
2026-04-14 start moving things into folders for sanity's sake
    [Backplane.kicad_pcb, cpu_operations.csv]
2026-04-16 just replace the asterisk on the first line of the disassembly instead of hanging onto the exact download
    [basic680.asm]
2026-04-19 commit-a-palooza after refactoring out the singleton on Machine, and upgrading to kicad 10
    [Jump.kicad_pcb, Jump.kicad_sch, Jump.step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]
2026-04-19 remove mockup
    [Jump.step, Time.kicad_pcb]
2026-04-26 lots of fixes to stack handling on emu, fix the latches on the banked memory board, tons of little bug fixes
    [B4PS-VH.stp, Backplane.kicad_pcb, BankedMemory.kicad_pcb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]
2026-11-03 lower case mod for flex, fix the backspace key in flex, make throttling optional, make tracing optional
2026-11-12 keyboard/sd board is getting there, deprecate previous attempts at sd/keyboad stuff in favour of this new one, adapt the avr firmwares to work with the new hardware
2026-11-12 be a bit more verbose on comments in the avr firmware
    addd an activity led using the spare 595 output
2026-11-13 update Math board
    rev 2 processor board, fix some missed connections, remove some non-required pull ups on address/data bus

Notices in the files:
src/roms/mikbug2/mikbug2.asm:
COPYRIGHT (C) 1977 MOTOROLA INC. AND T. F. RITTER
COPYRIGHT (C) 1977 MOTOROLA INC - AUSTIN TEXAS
